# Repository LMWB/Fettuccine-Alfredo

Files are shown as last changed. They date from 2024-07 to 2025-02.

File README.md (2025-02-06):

# Fettuccine-Alfredo
very basic and cheap constant current circuit for medium power LED's

This project is about to design a very simple LED driver circuit for medium power LED's. I'd like to play around with different LED color temperatures and shapes. 

# Simulations and Schematics
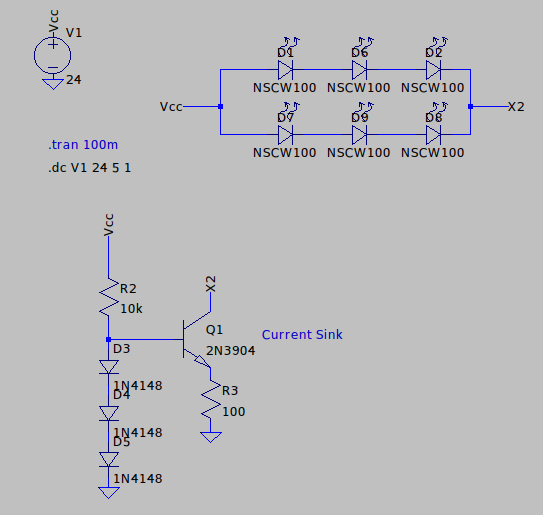
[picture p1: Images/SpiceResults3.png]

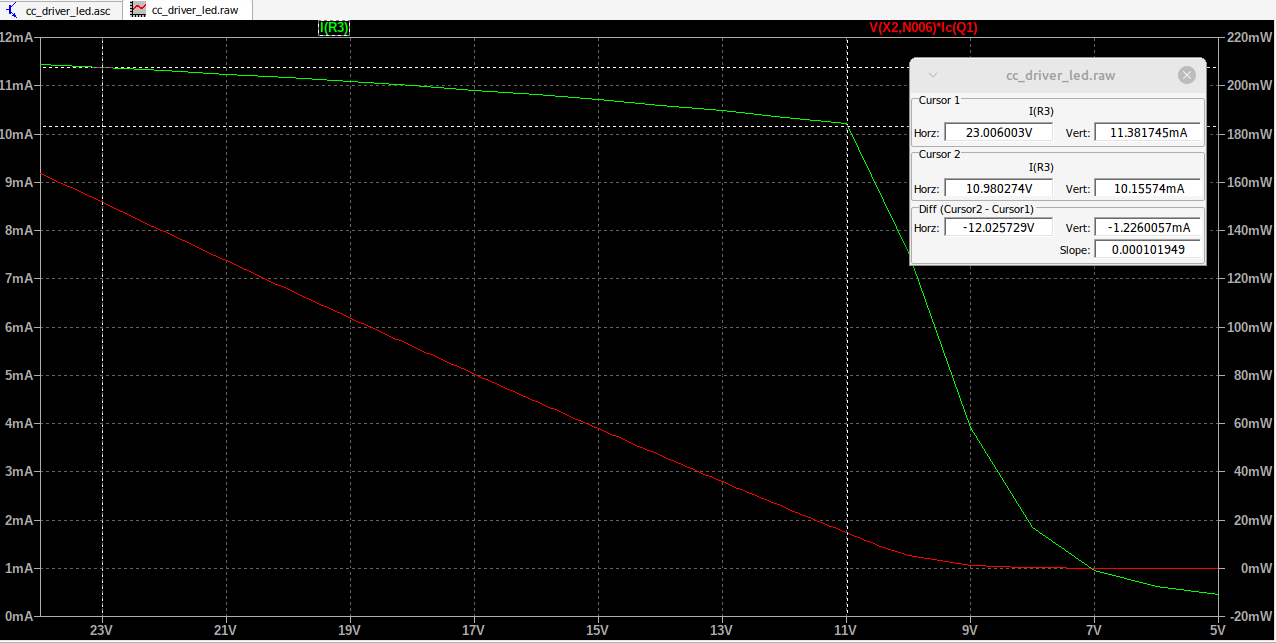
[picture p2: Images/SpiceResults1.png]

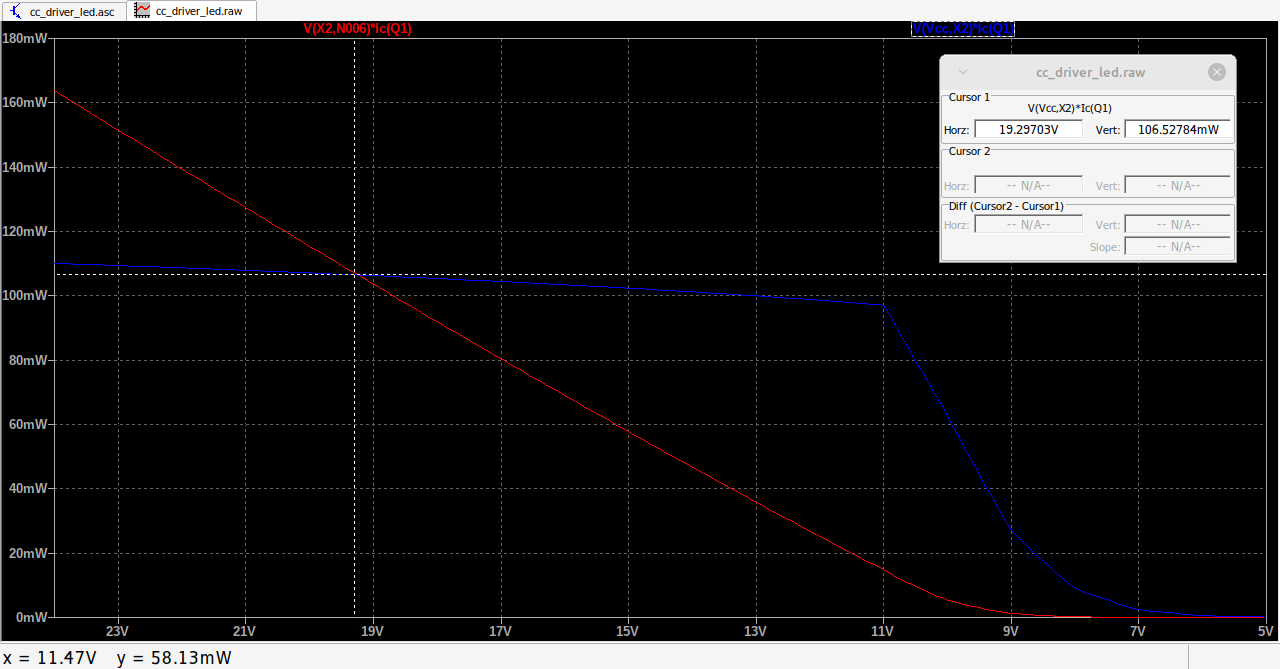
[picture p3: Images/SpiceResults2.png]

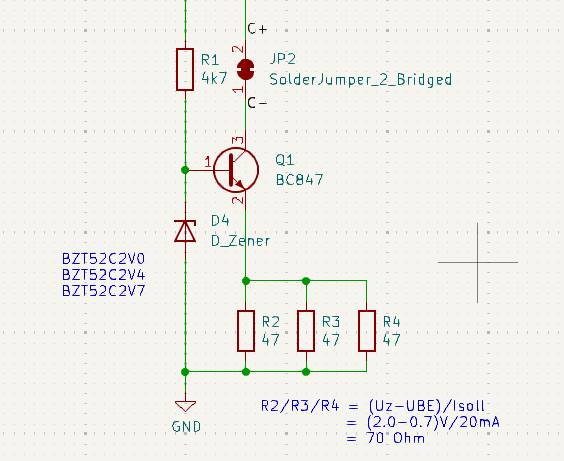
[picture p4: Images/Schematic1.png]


# Adjusting Current
```math
I_{LED} \approx I_{R_S} = \frac{U_{D} - U_{BE}}{R_S}  
```

```math
I_{LED} = \frac{1.8 V - 0.7 V}{100 \Omega} = 11mA  
```

## Revision 0 uses PLCC 2835 LED Footprint and 3528 (alternative)
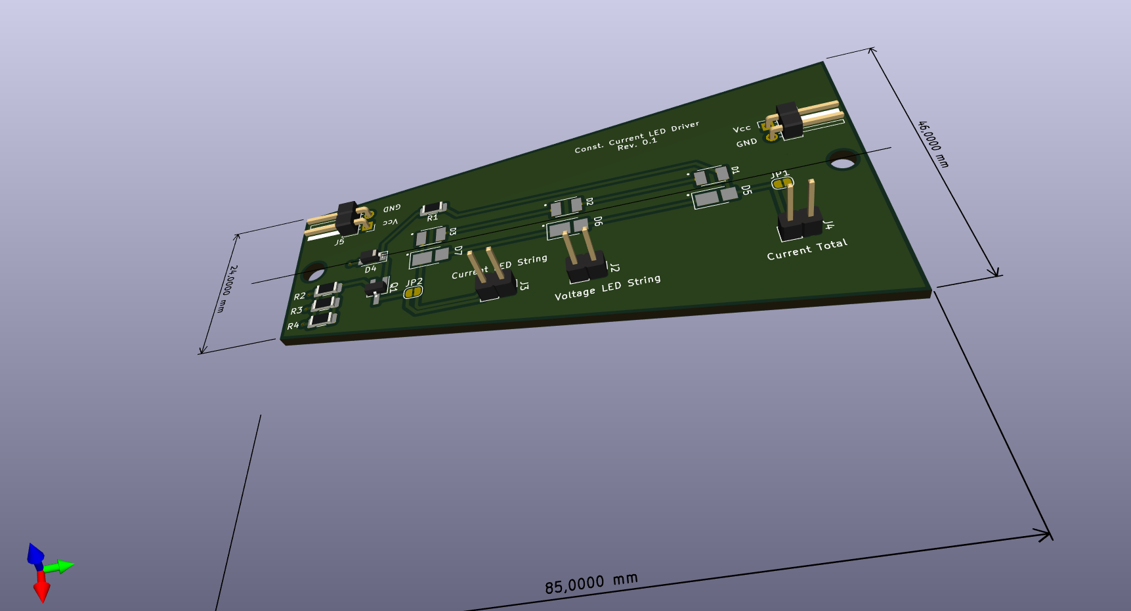
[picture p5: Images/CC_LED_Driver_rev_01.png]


## Revision 1 uses 3528 Footprint only
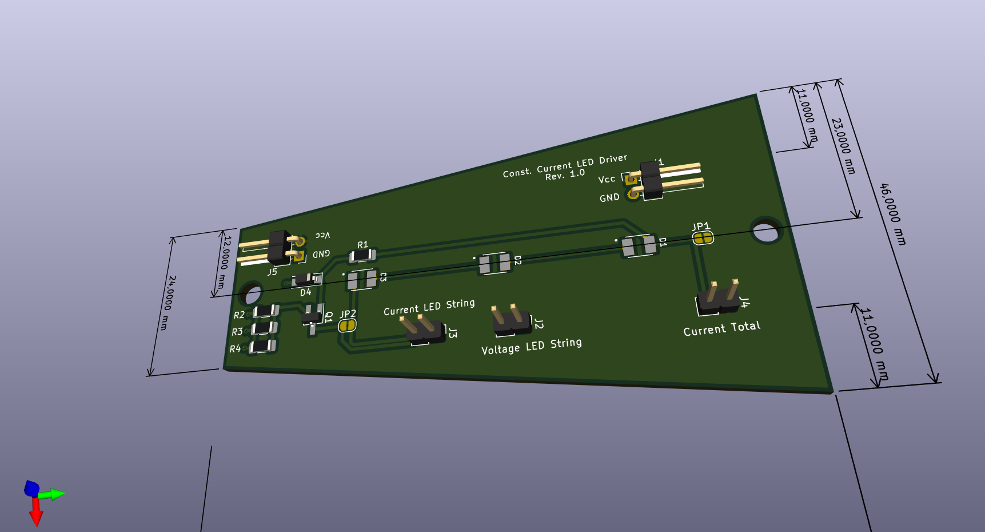
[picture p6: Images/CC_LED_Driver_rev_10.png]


# Real World Examples
## Street Light
## Lamp
I used the [timer clock project](https://github.com/LMWB/Cannelloni-al-Forno) and three of this LED boards to create a illumination of my courtyard.  
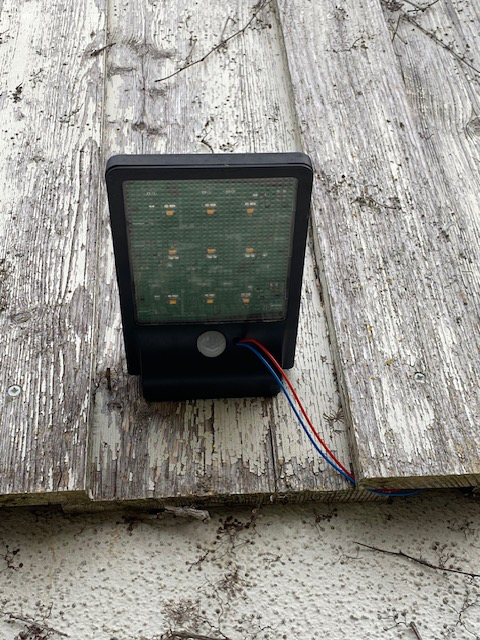
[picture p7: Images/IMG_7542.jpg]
  
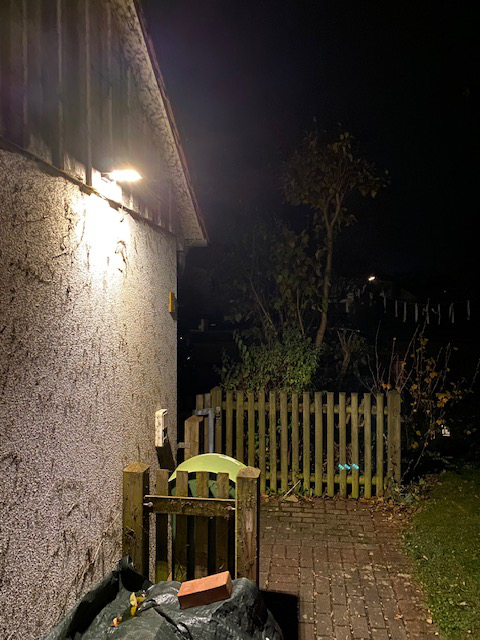
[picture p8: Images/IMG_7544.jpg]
  
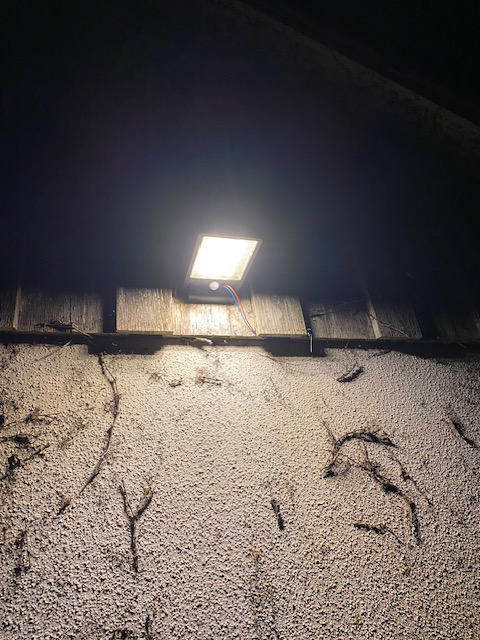
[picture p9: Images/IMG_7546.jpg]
  

## X-Mas Star
I also used the [timer clock project](https://github.com/LMWB/Cannelloni-al-Forno) and three of this LED boards in a three-dimensional setup to create a kind of LED light build to use in a outdoor christmas decoration.  
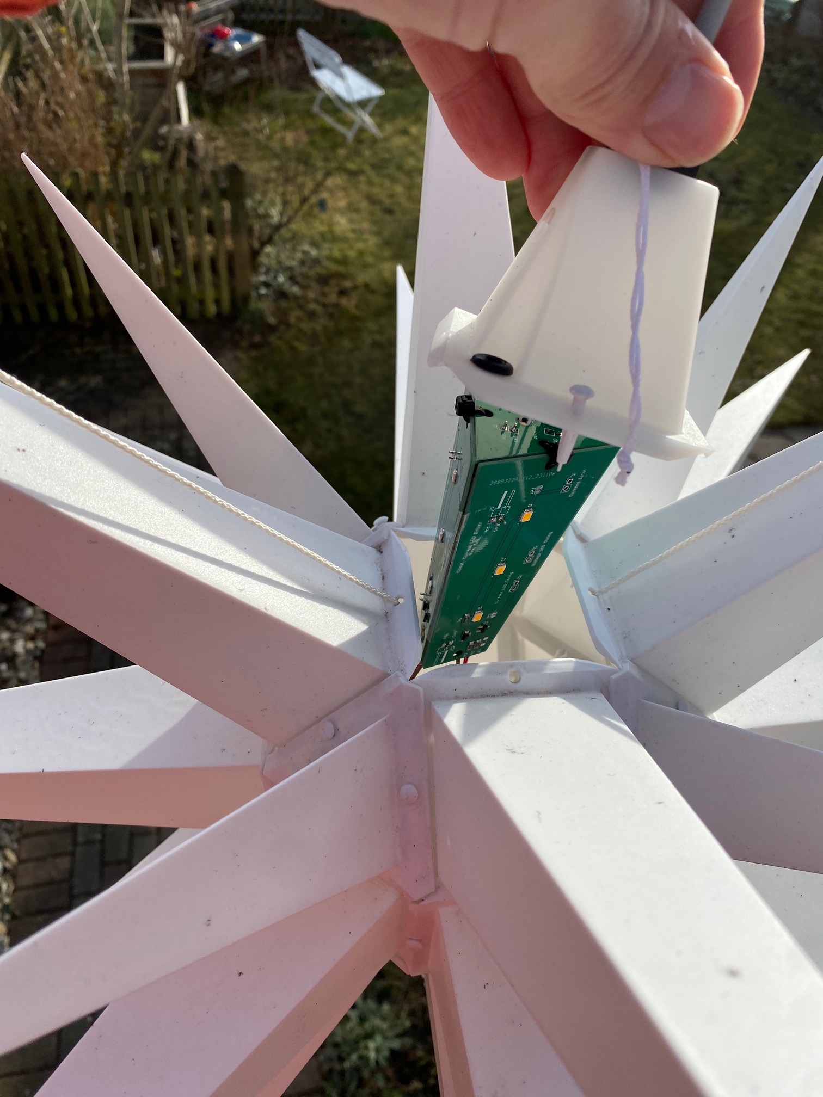
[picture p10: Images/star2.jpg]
Star Light
  
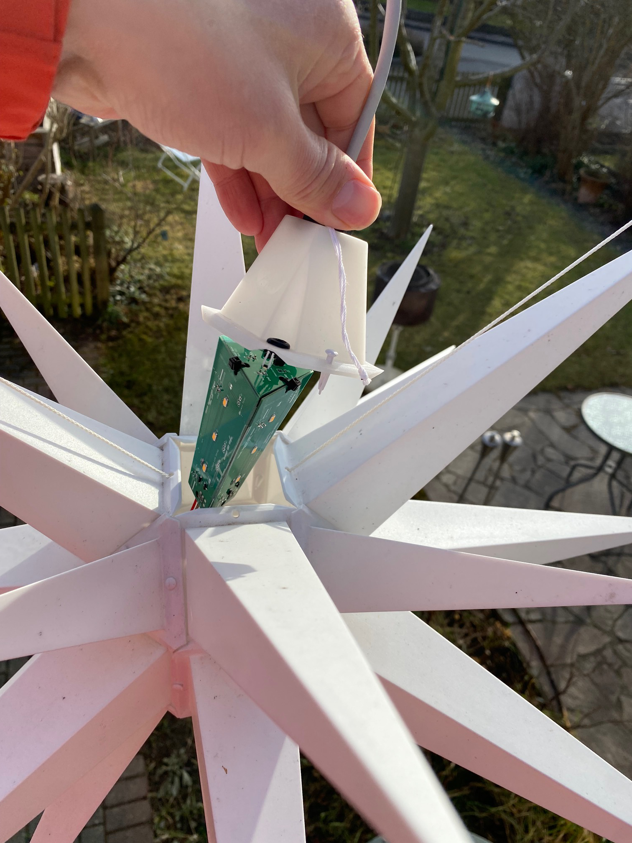
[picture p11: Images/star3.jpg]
Star Light
  
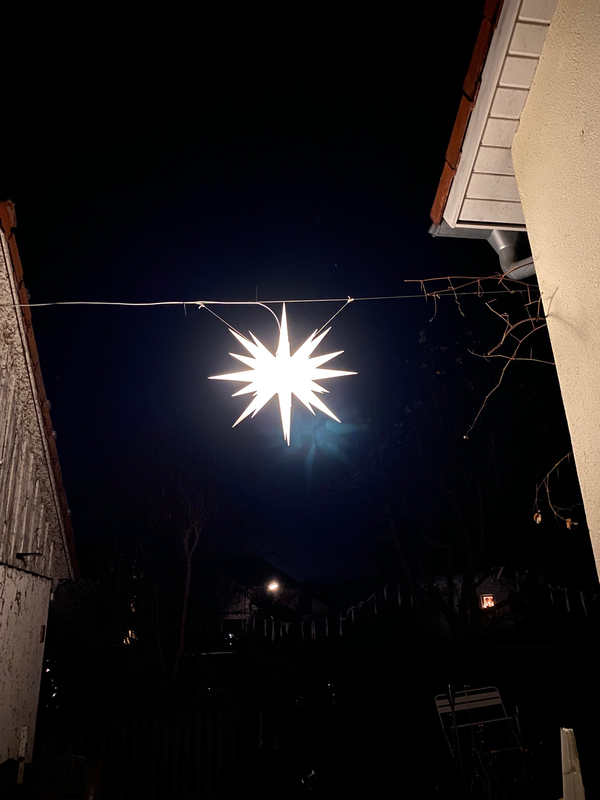
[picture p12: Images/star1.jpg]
Star Light
  

# Sources
## Material
high performance power LED found on ebay  
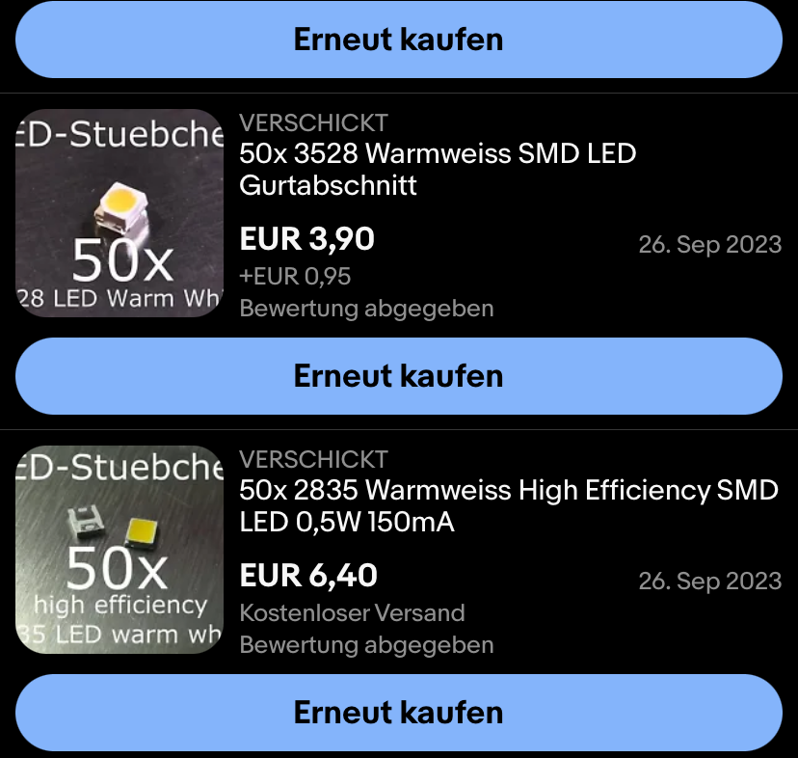
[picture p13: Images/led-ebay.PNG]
LED warm white


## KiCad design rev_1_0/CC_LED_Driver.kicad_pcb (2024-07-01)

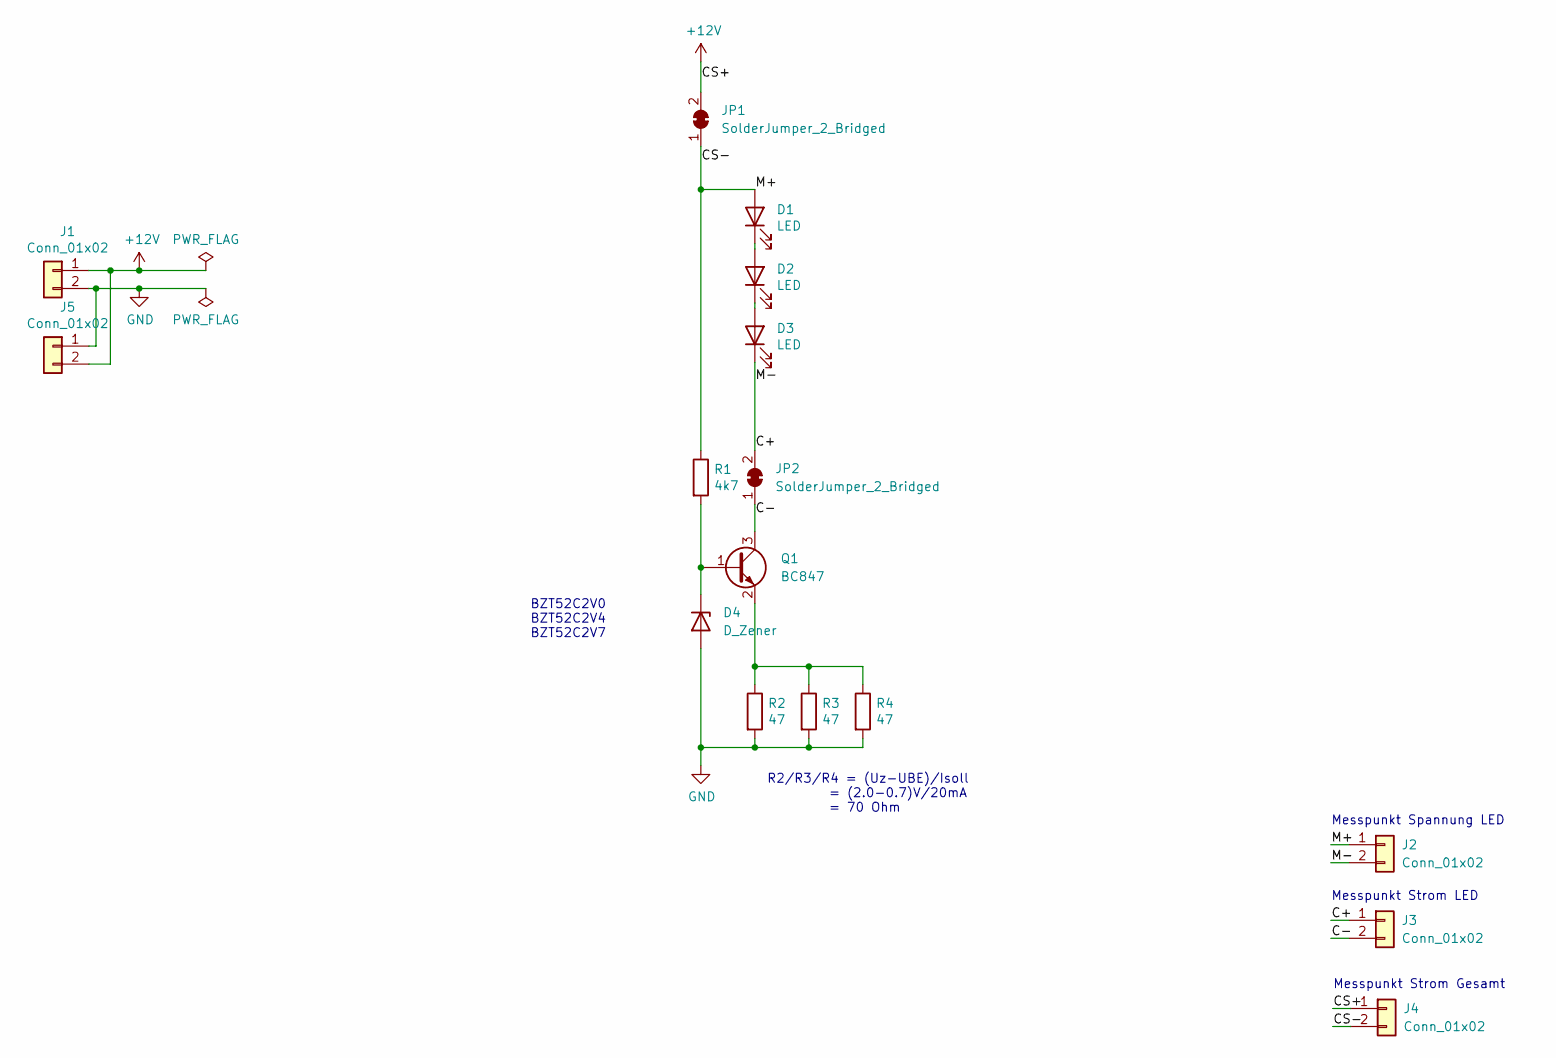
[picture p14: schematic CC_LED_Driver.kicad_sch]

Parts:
D1, D2, D3: LED; LED_3528_Handsolder_XL
D4: D_Zener; D_SOD-123_HandsolderXL
J1, J5: Conn_01x02; PinHeader_1x02_P2.54mm_Horizontal
J2, J3, J4: Conn_01x02; PinHeader_1x02_P2.54mm_Vertical
JP1, JP2: SolderJumper_2_Bridged; SolderJumper-2_P1.3mm_Bridged2Bar_RoundedPad1.0x1.5mm
Q1: BC847; SOT-23_Handsoldering
R1: 4k7; R_1206_3216Metric_Pad1.30x1.75mm_HandSolder
R2, R3, R4: 47; R_1206_3216Metric_Pad1.30x1.75mm_HandSolder

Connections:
+12V: J1.1, J4.1, J5.2, JP1.2 (B)
/C+: D3.1 (K), J2.2, J3.1, JP2.2 (B)
/C-: J3.2, JP2.1 (A), Q1.3 (C)
/CS-: D1.2 (A), J2.1, J4.2, JP1.1 (A), R1.1
GND: D4.2 (A), J1.2, J5.1, R2.2, R3.2, R4.2
unnamed: D1.1 (K), D2.2 (A)
unnamed: D2.1 (K), D3.2 (A)
unnamed: D4.1 (K), Q1.1 (B), R1.2
unnamed: Q1.2 (E), R2.1, R3.1, R4.1

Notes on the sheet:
R2/R3/R4 = (Uz-UBE)/Isoll = (2.0-0.7)V/20mA = 70 Ohm
Messpunkt Strom LED
BZT52C2V0 BZT52C2V4 BZT52C2V7
Messpunkt Spannung LED
Messpunkt Strom Gesamt

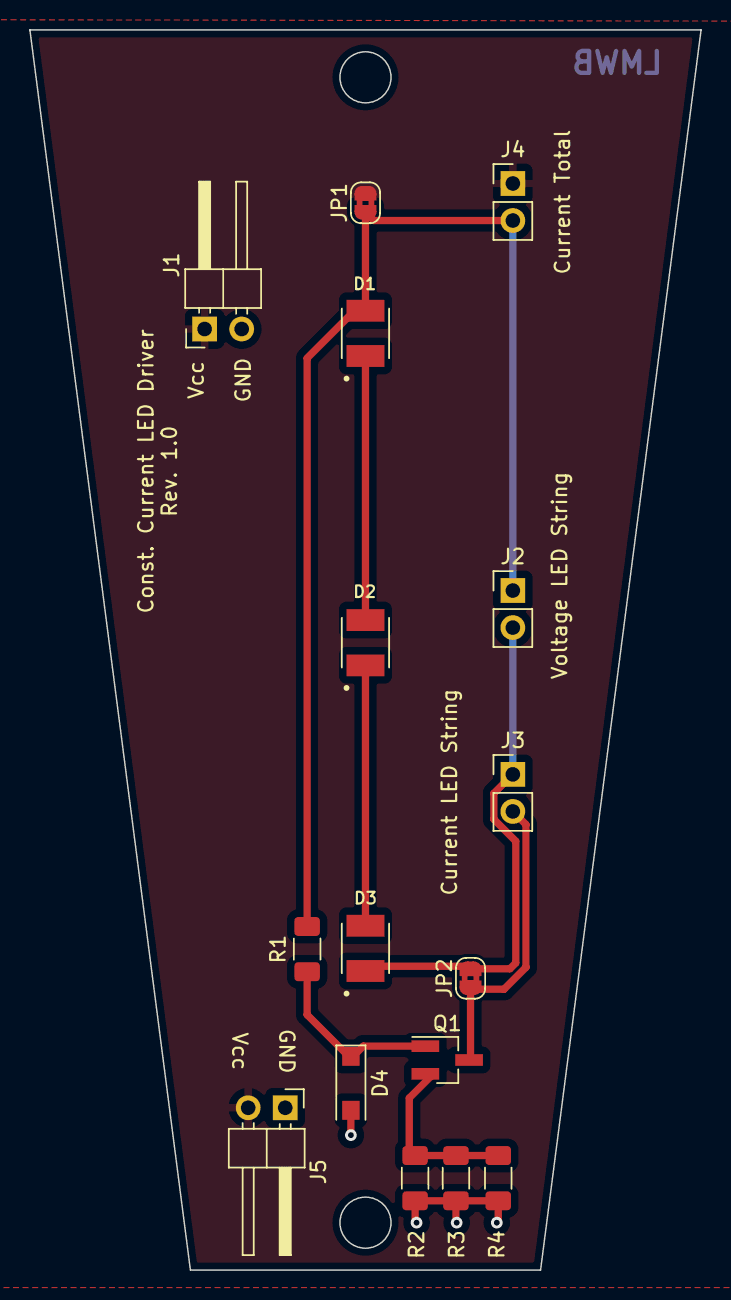
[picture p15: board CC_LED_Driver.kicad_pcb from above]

Board: 2 copper layers, 46.0 x 85.0 mm, 16 parts (0 on the bottom side), 9 nets.

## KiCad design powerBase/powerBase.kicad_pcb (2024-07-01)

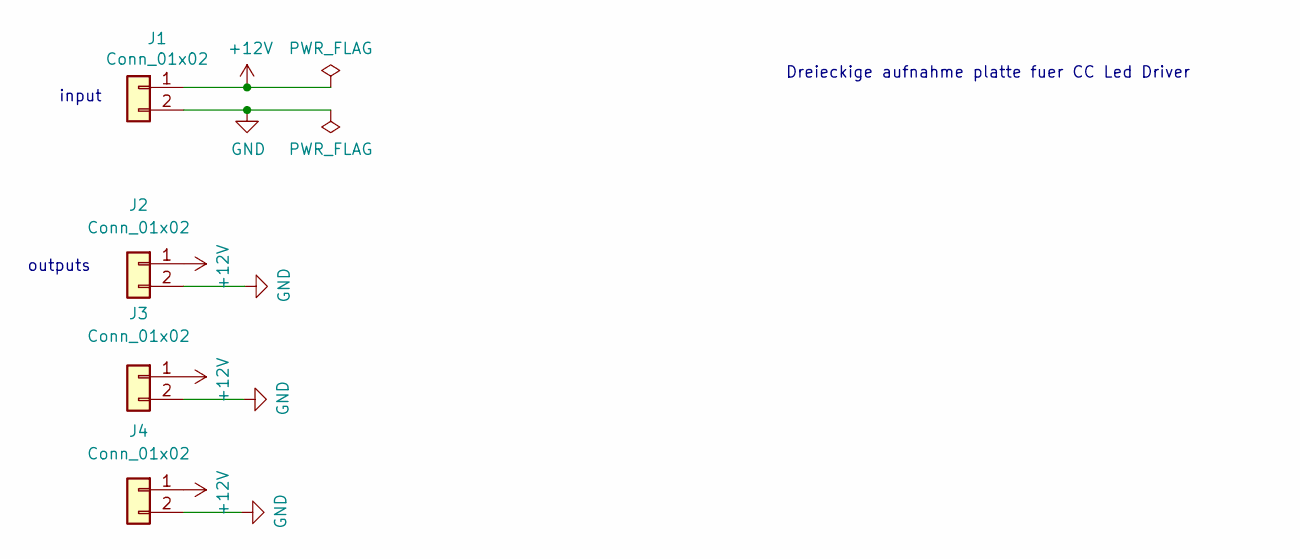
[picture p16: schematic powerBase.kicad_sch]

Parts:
J1, J2, J3, J4: Conn_01x02; PinHeader_1x02_P2.54mm_Vertical

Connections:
+12V: J1.1, J2.1, J3.1, J4.1
GND: J1.2, J2.2, J3.2, J4.2

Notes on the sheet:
Dreieckige aufnahme platte fuer CC Led Driver
input
outputs

Board: 2 copper layers, 4 parts (0 on the bottom side), 2 nets, no tracks yet.

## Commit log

2024-07-01 add kicad files
    [CC_LED_Driver-B_Cu.gbl, CC_LED_Driver-B_Mask.gbs, CC_LED_Driver-B_Paste.gbp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]
2024-12-23 added schematics
